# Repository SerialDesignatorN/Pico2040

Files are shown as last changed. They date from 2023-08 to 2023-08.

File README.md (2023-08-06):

# Pico2040
RP2040-based dev board designed in KiCad.
## Required libraries (in order to change some items):
- TL3365AF180QG ***(found easily on SnapEDA)***
# Recommended ordering options
For the Pico2040, ordering via JLCPCB is recommended. Here are some recommended settings for ordering from each manufacturer:
## JLCPCB
- Base Material: **FR-4**
- Layers: **2** (do not change)
- PCB Qty: ***up to you (max is 30 to prevent black market revenue)***
- Different Designs: **1** (do not change)
- Delivery Format: **Either *"Single PCB"* or *"Panel by JLCPCB"***
- PCB thickness: **1.6mm**
- PCB color: **Green**
Don't change anything else after the settings I mentioned

## PCBWay
- Board Type: **Single Pieces**
- Different design in panel: **1**
- Quantity: ***up to you (max is 30 to prevent black market revenue)***
- Layers: **2** (do not change)
- Material: **FR-4**
- FR4-TG: **TG150-160**
- Thickness: **1.6mm**
- Min track/spacing: **4/4mil**
- Min hole size: **0.3mm**
- Solder Mask: **Green**
Don't change anything else after the settings I mentioned

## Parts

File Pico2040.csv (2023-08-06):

Id | Designator | Footprint | Quantity | Designation | Supplier and ref
1 | J1 | USB_Micro-B_Amphenol_10103594-0001LF_Horizontal | 1 | USB_B_Micro
2 | R1,R2,R3 | R_0201_0603Metric_Pad0.64x0.40mm_HandSolder | 3 | R
3 | D1 | LED_0201_0603Metric | 1 | LED
4 | J2,J3 | PinHeader_1x20_P2.00mm_Vertical | 2 | Conn_01x20
5 | C13,C14,C3,C8,C11,C6,C4,C5,C7,C10,C2,C9,C1,C12 | C_0201_0603Metric_Pad0.64x0.40mm_HandSolder | 14 | C
6 | S2,S1 | SW_TL3365AF180QG | 2 | TL3365AF180QG
7 | D2,D3 | LED_0201_0603Metric_Pad0.64x0.40mm_HandSolder | 2 | LED
8 | Y1 | Crystal_SMD_EuroQuartz_X22-4Pin_2.5x2.0mm | 1 | Crystal_GND24_Small
9 | U2 | QFN-56-1EP_7x7mm_P0.4mm_EP3.2x3.2mm | 1 | RP2040
10 | J4 | PinHeader_1x03_P2.00mm_Vertical | 1 | Conn_01x03
11 | TP1 | TestPoint_Pad_1.0x1.0mm | 1 | RESET
12 | TP2 | TestPoint_Pad_1.0x1.0mm | 1 | USB_DP
13 | TP4 | TestPoint_Pad_1.0x1.0mm | 1 | BOOTSEL
14 | U3 | SOIC-8_5.23x5.23mm_P1.27mm | 1 | W25Q32JVSS
15 | U1 | SOT-23-5 | 1 | MIC5205-3.3YM5
16 | TP3 | TestPoint_Pad_1.0x1.0mm | 1 | USB_DM

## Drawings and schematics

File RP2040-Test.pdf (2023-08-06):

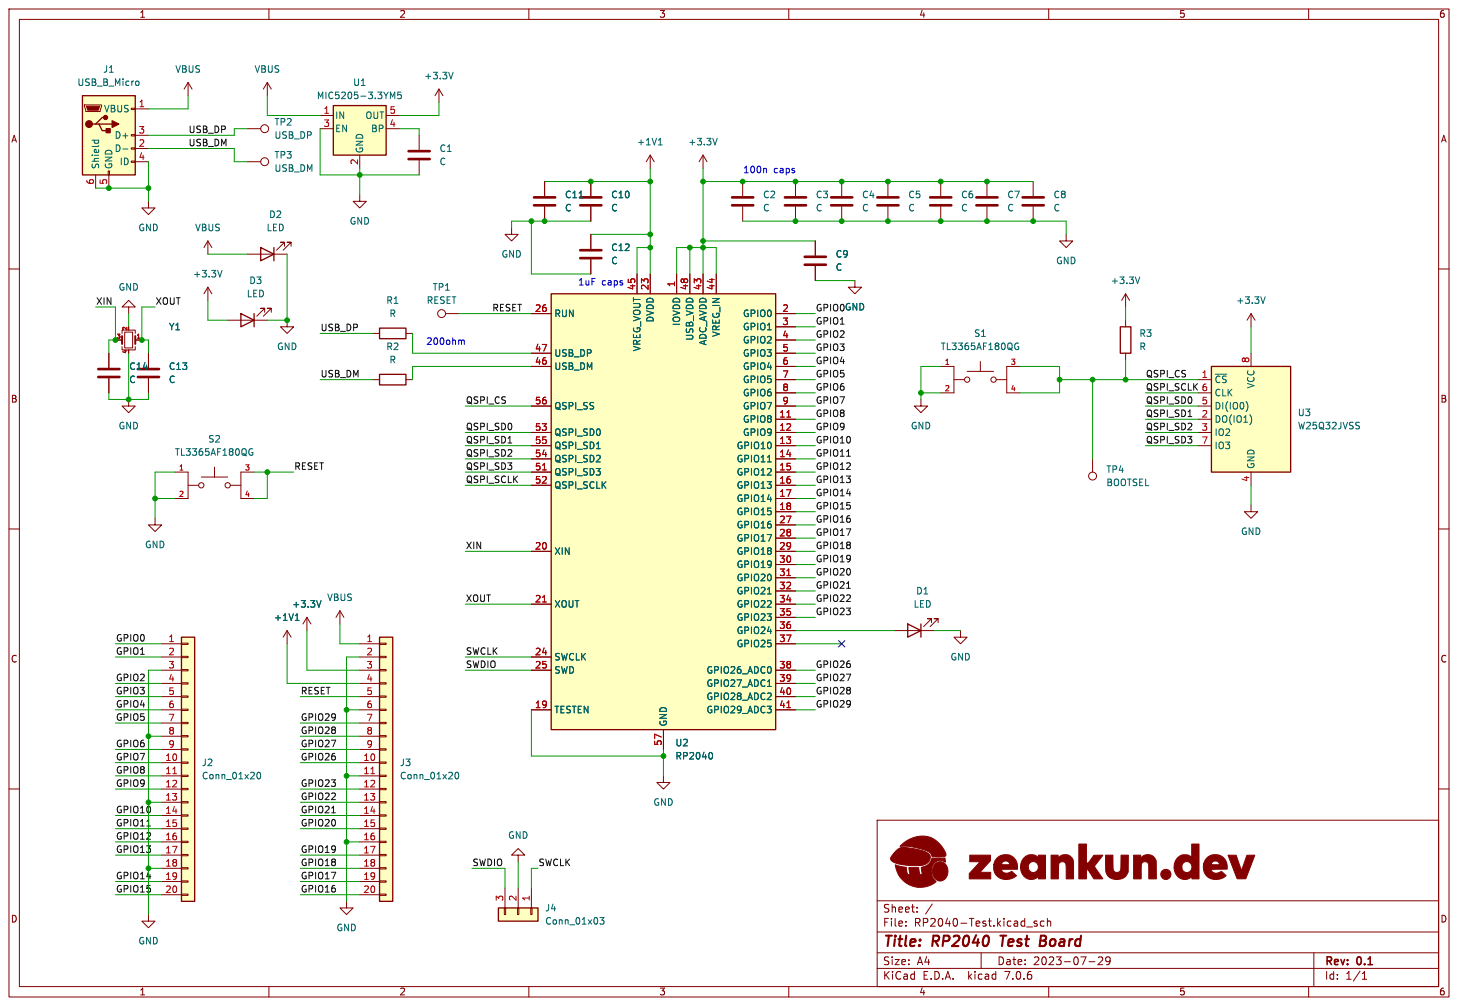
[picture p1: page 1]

2 EN 3 BP 4 OUT 5 U1 MIC5205-3.3YM5 C14 C GND

1 GPIO8 11 GPIO9 12 GPIO10 13 GPIO11 14 GPIO12 15 GPIO13 16 GPIO14 17 GPIO15 18 TESTEN 19 GPIO0 2 XIN 20 XOUT 21 DVDD 23 SWCLK 24 SWD 25 RUN 26 GPIO16 27 GPIO17 28 GPIO18 29 GPIO1 3 GPIO19 30 GPIO20 31 GPIO21 32 GPIO22 34 GPIO23 35 GPIO24 36 GPIO25 37 GPIO26_ADC0 38 GPIO27_ADC1 39 GPIO2 4 GPIO28_ADC2 40 GPIO29_ADC3 41 ADC_AVDD 43 VREG_IN 44 VREG_VOUT 45 USB_DM 46 USB_DP 47 USB_VDD 48 GPIO3 5 QSPI_SD3 51 QSPI_SCLK 52 QSPI_SD0 53 QSPI_SD2 54 QSPI_SD1 55 QSPI_SS 56 GND 57 GPIO4 6 GPIO5 7 GPIO6 8 GPIO7 9 C9 C GND

1 GPIO8 11 GPIO9 12 GPIO10 13 GPIO11 14 GPIO12 15 GPIO13 16 GPIO14 17 GPIO15 18 TESTEN 19 GPIO0 2 XIN 20 XOUT 21 DVDD 23 SWCLK 24 SWD 25 RUN 26 GPIO16 27 GPIO17 28 GPIO18 29 GPIO1 3 GPIO19 30 GPIO20 31 GPIO21 32 GPIO22 34 GPIO23 35 GPIO24 36 GPIO25 37 GPIO26_ADC0 38 GPIO27_ADC1 39 GPIO2 4 GPIO28_ADC2 40 GPIO29_ADC3 41 ADC_AVDD 43 VREG_IN 44 VREG_VOUT 45 USB_DM 46 USB_DP 47 USB_VDD 48 GPIO3 5 QSPI_SD3 51 QSPI_SCLK 52 QSPI_SD0 53 QSPI_SD2 54 QSPI_SD1 55 QSPI_SS 56 GND 57 GPIO4 6 GPIO5 7 GPIO6 8 GPIO7 9 U2 RP2040 D1

File: RP2040-Test.kicad_sch Sheet: /
Id: 1/1 Title: RP2040 Test Board

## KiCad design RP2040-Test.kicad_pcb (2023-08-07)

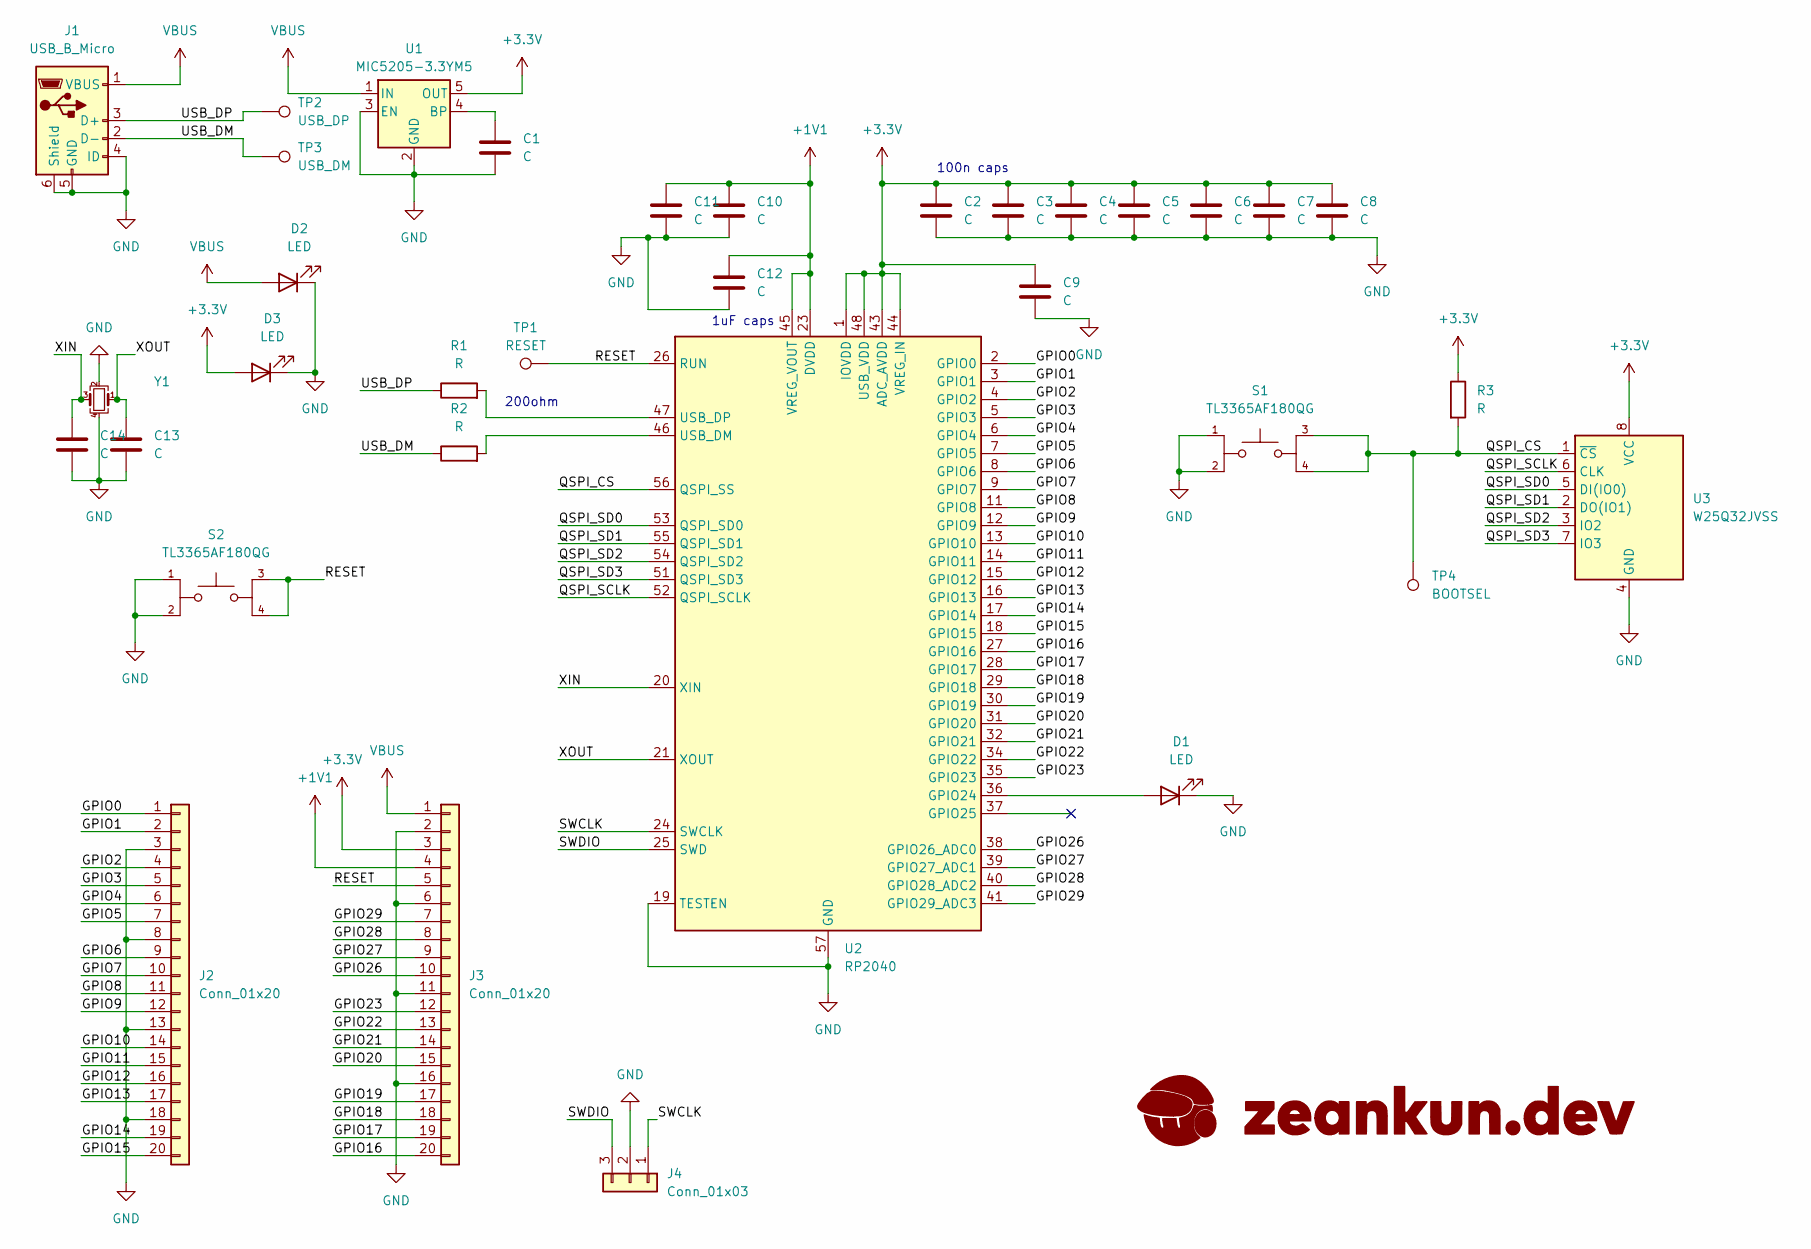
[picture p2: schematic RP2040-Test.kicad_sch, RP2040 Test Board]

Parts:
C1, C2, C3, C4, C5, C6, C7, C8, C9, C10, C11, C12, C13, C14: C; C_0201_0603Metric
D1, D2, D3: LED; LED_0201_0603Metric
J1: USB_B_Micro; USB_Micro-B_Amphenol_10103594-0001LF_Horizontal
J2, J3: Conn_01x20; PinHeader_1x20_P2.00mm_Vertical
J4: Conn_01x03; PinHeader_1x03_P2.00mm_Vertical
R1, R2, R3: R; R_0201_0603Metric
S1, S2: TL3365AF180QG; SW_TL3365AF180QG; PARTREV A
TP1: RESET; TestPoint_Pad_1.0x1.0mm
TP2: USB_DP; TestPoint_Pad_1.0x1.0mm
TP3: USB_DM; TestPoint_Pad_1.0x1.0mm
TP4: BOOTSEL; TestPoint_Pad_1.0x1.0mm
U1: MIC5205-3.3YM5; SOT-23-5
U2: RP2040; QFN-56-1EP_7x7mm_P0.4mm_EP3.2x3.2mm
U3: W25Q32JVSS; SOIC-8_5.23x5.23mm_P1.27mm
Y1: Crystal_GND24_Small; Crystal_SMD_EuroQuartz_X22-4Pin_2.5x2.0mm

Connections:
+1V1: C10.1, C11.1, C12.1, J3.4, U2.23 (DVDD), U2.45 (VREG_VOUT), U2.50 (DVDD)
+3.3V: C2.1, C3.1, C4.1, C5.1, C6.1, C7.1, C8.1, C9.1, D3.2 (A), J3.3, R3.1, U1.5 (OUT), U2.1 (IOVDD), U2.10 (IOVDD), U2.22 (IOVDD), U2.33 (IOVDD), U2.42 (IOVDD), U2.43 (ADC_AVDD), U2.44 (VREG_IN), U2.48 (USB_VDD), U2.49 (IOVDD), U3.8 (VCC)
/GPIO0: J2.1, U2.2 (GPIO0)
/GPIO1: J2.2, U2.3 (GPIO1)
/GPIO2: J2.4, U2.4 (GPIO2)
/GPIO3: J2.5, U2.5 (GPIO3)
/GPIO4: J2.6, U2.6 (GPIO4)
/GPIO5: J2.7, U2.7 (GPIO5)
/GPIO6: J2.9, U2.8 (GPIO6)
/GPIO7: J2.10, U2.9 (GPIO7)
/GPIO8: J2.11, U2.11 (GPIO8)
/GPIO9: J2.12, U2.12 (GPIO9)
/GPIO10: J2.14, U2.13 (GPIO10)
/GPIO11: J2.15, U2.14 (GPIO11)
/GPIO12: J2.16, U2.15 (GPIO12)
/GPIO13: J2.17, U2.16 (GPIO13)
/GPIO14: J2.19, U2.17 (GPIO14)
/GPIO15: J2.20, U2.18 (GPIO15)
/GPIO16: J3.20, U2.27 (GPIO16)
/GPIO17: J3.19, U2.28 (GPIO17)
/GPIO18: J3.18, U2.29 (GPIO18)
/GPIO19: J3.17, U2.30 (GPIO19)
/GPIO20: J3.15, U2.31 (GPIO20)
/GPIO21: J3.14, U2.32 (GPIO21)
/GPIO22: J3.13, U2.34 (GPIO22)
/GPIO23: J3.12, U2.35 (GPIO23)
/GPIO26: J3.10, U2.38 (GPIO26_ADC0)
/GPIO27: J3.9, U2.39 (GPIO27_ADC1)
/GPIO28: J3.8, U2.40 (GPIO28_ADC2)
/GPIO29: J3.7, U2.41 (GPIO29_ADC3)
/QSPI_CS: R3.2, S1.3, S1.4, TP4.1, U2.56 (QSPI_SS), U3.1 (~CS)
/QSPI_SCLK: U2.52 (QSPI_SCLK), U3.6 (CLK)
/QSPI_SD0: U2.53 (QSPI_SD0), U3.5 (DI(IO0))
/QSPI_SD1: U2.55 (QSPI_SD1), U3.2 (DO(IO1))
/QSPI_SD2: U2.54 (QSPI_SD2), U3.3 (IO2)
/QSPI_SD3: U2.51 (QSPI_SD3), U3.7 (IO3)
/RESET: J3.5, S2.3, S2.4, TP1.1, U2.26 (RUN)
/SWCLK: J4.1, U2.24 (SWCLK)
/SWDIO: J4.3, U2.25 (SWD)
/USB_DM: J1.2 (D-), R2.1, TP3.1
/USB_DP: J1.3 (D+), R1.1, TP2.1
/XIN: C14.1, U2.20 (XIN), Y1.3
/XOUT: C13.1, U2.21 (XOUT), Y1.1
GND: C1.2, C2.2, C3.2, C4.2, C5.2, C6.2, C7.2, C8.2, C9.2, C10.2, C11.2, C12.2, C13.2, C14.2, D1.1 (K), D2.1 (K), D3.1 (K), J1.4 (ID), J1.5 (GND), J1.6 (Shield), J2.3, J2.8, J2.13, J2.18, J3.2, J3.6, J3.11, J3.16, J4.2, S1.1, S1.2, S2.1, S2.2, U1.2 (GND), U1.3 (EN), U2.19 (TESTEN), U2.57 (GND), U3.4 (GND), Y1.2, Y1.4
unnamed: D1.2 (A), U2.36 (GPIO24)
unnamed: C1.1, U1.4 (BP)
unnamed: R2.2, U2.46 (USB_DM)
unnamed: R1.2, U2.47 (USB_DP)
VBUS: D2.2 (A), J1.1 (VBUS), J3.1, U1.1 (IN)

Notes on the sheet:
1uF caps
200ohm
100n caps

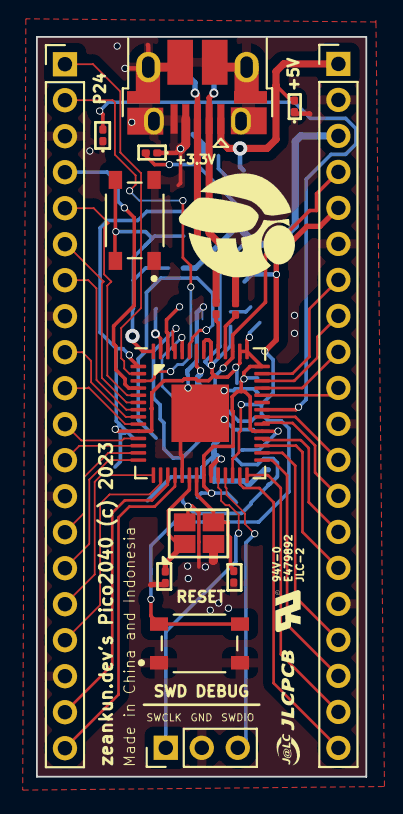
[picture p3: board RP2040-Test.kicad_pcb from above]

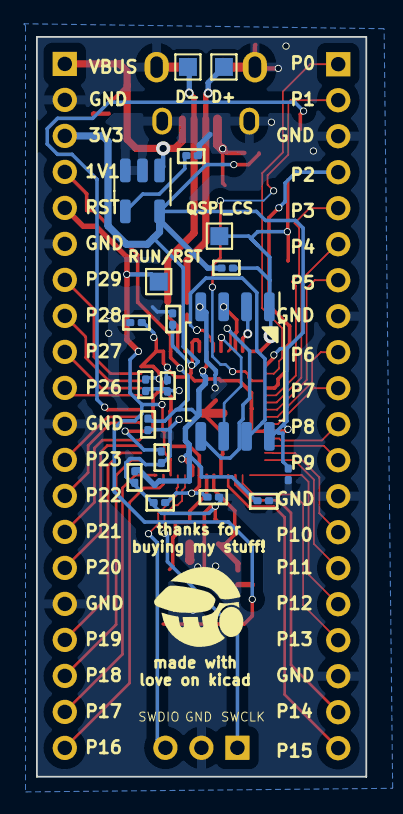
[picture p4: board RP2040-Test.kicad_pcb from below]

Board: 2 copper layers, 18.3 x 41.1 mm, 34 parts (19 on the bottom side), 49 nets.

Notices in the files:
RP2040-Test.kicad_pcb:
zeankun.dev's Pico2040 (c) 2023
